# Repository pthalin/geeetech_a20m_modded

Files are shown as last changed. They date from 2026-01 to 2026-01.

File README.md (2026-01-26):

# Geeetech A20M Modded

I had a ton of problems with my Geeetech A20M when printing PETG. Bad quality prints, Fillamnt stick on the nozzle, Hotend clogs, Print not sticking to build plate, and so on. Therefore I decide to rebuild it to better fit my needs. After these changes it feels like a whole new printer! This is not a complet guide but if you are a tinker it should be enough to get you going. If you like this feel free to use the sponsored links below to support me! 

Donation using [Ko-Fi](https://ko-fi.com/patriksretrotech) or [PayPal](https://www.paypal.com/donate/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) are highly appreciated!

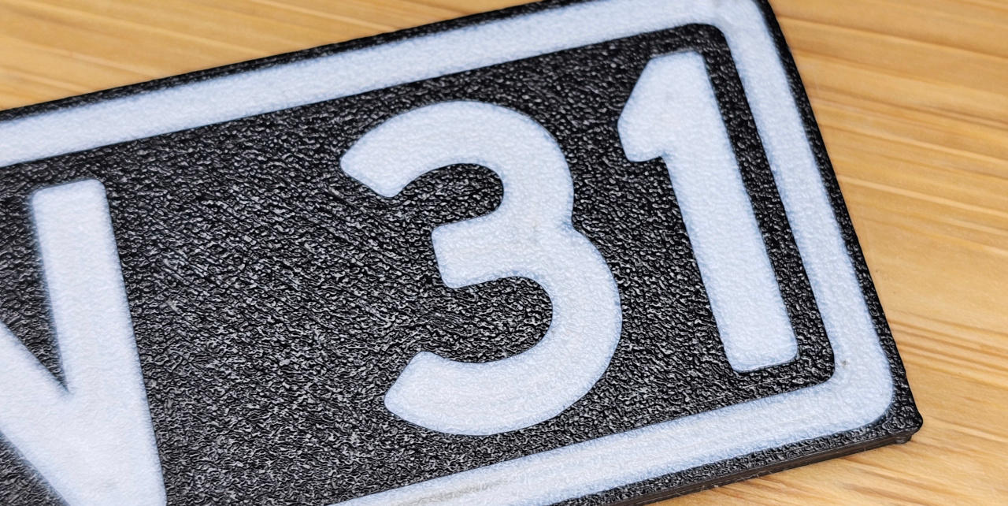
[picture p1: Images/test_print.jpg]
 

Parts (AliExpress):\
[XCR3D 2 IN 1 OUT Hotend with Heater and Sensor](https://s.click.aliexpress.com/e/_c3dWIA2b)\
[BMG Extruders Full Metal (2x Right)](https://s.click.aliexpress.com/e/_c3lZYPxh)\
[Trianglelab 3D Touch](https://s.click.aliexpress.com/e/_c2QazP8F) + [Short cable with dupont connector](https://s.click.aliexpress.com/e/_c3YiJ9rv)\
[PEI Build Plate with magnetic base](https://s.click.aliexpress.com/e/_c3RffY35)

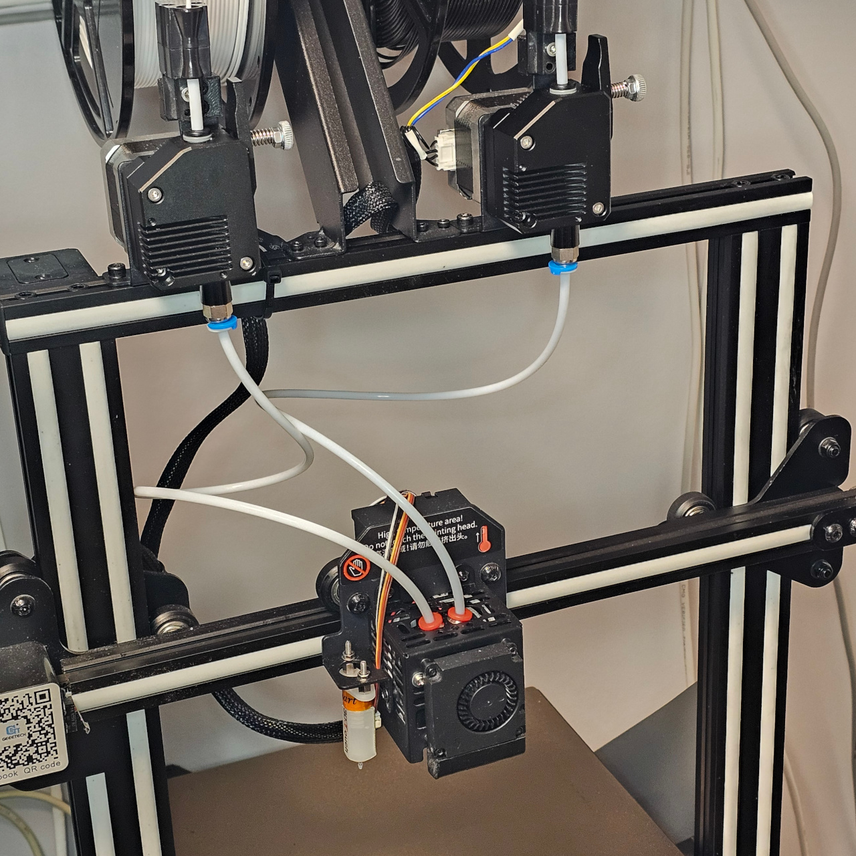
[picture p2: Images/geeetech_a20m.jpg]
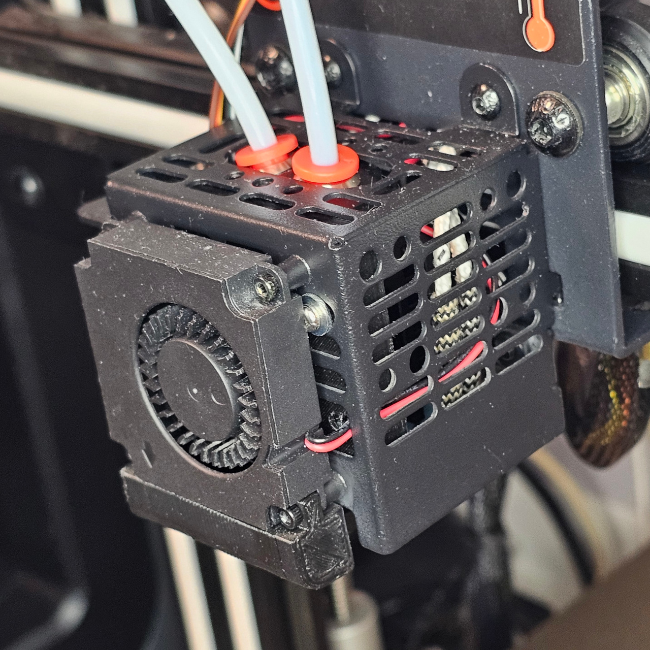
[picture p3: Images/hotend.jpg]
 

To mount the new Hotend a [mounting plate](Hotend/hotend_mount.stl) needs to be printed. 

Wiring of hotend\
 

For the modifications a custom config of [Marlin 2.0 firmware](Marlin/) is needed.\
Build it with [Visual Studio Code](https://code.visualstudio.com/download) using the [Auto Build Marlin](https://marlinfw.org/docs/basics/auto_build_marlin.html) extension to build and flash the firmware.

**IMPORTANT!** Do these steps BEFORE trying to do any prints:
1. Z-offset needs to be set correctly.
2. Run auto bed leveling.
3. Do first layer calibration.
4. Use the calibration in OrcaSlicer to fine tune your settings.

I use OrcaSlicer with the these settings: [Exported Settings](OrcaSlicer/)

I also run a Raspberry Pi with Octopi. This is convenient as you can upload print directly from OrcaSlice without fiddeling with SD Cards. I have added a realy on the cords to the printer so I can start it remotely. \
Install Octopi with Raspberry Pi Imager and load [config backup](Octopi/) (User/Password: octopi/octopi).

I strongly recommand buying a simple a fillamnt dryer. I was sceptical but this gives a huge improvement in the print results with smoother surfaces! I use a [Sunlu S2 Filament Dryer](https://s.click.aliexpress.com/e/_c3yCW3Xv)

XCR3D 2 In 1 out hotend. Not mixing colors, but PEGT is not mixing well anyway and I prefere clean colors.\
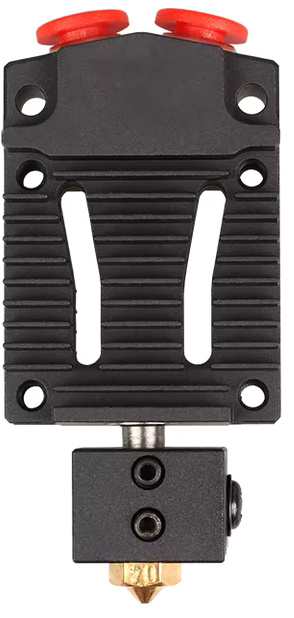
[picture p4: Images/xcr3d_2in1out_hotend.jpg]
[](https://s.click.aliexpress.com/e/_c3dWIA2b)

BMG Extruder with dual gears that ensure consisten feeding.\
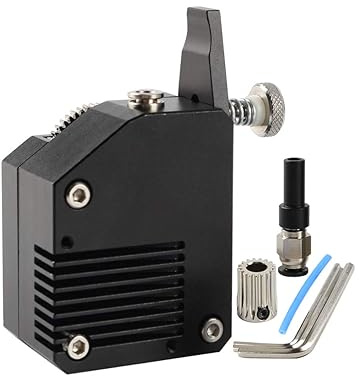
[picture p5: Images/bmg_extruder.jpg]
[](https://s.click.aliexpress.com/e/_c3lZYPxh)

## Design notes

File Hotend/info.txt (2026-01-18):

Downloaded from:
https://cults3d.com/en/3d-model/tool/btt-2-in-1-out-mount-revised-a10m

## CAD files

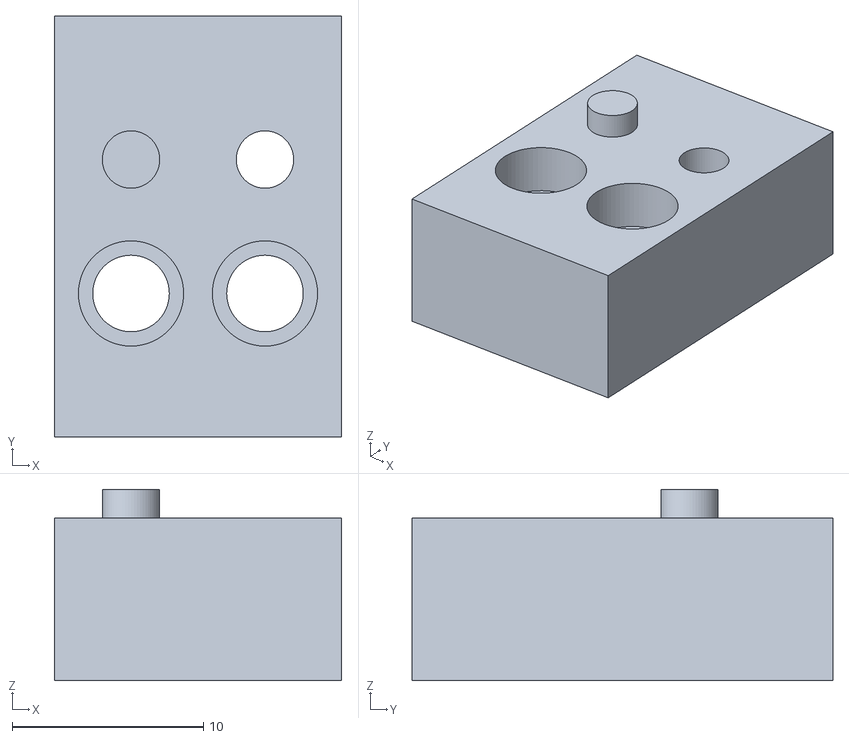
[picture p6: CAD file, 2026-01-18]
FilamentSensor/sensor_plate_a20m.stl
15.0 x 22.0 x 10.0

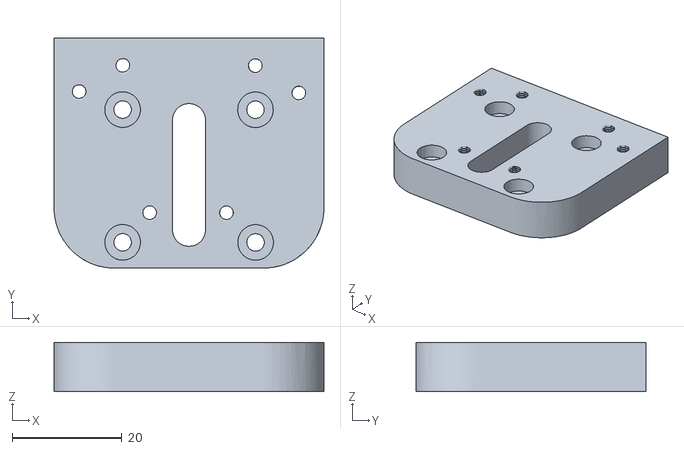
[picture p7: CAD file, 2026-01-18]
Hotend/hotend_mount.stl
49.2 x 42.0 x 9.00

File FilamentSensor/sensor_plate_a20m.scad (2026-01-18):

d = 4;
h=8.5;
b=22;
l=15;
cc=7;
OF = 7;
FNN = 60;
    union() {
difference() {
    cube([l,b,h],center=false);
        union() {
            translate([4,7.5,0]) cylinder(h=40, r=d/2, $fn=FNN, center=true);
            translate([4+cc,7.5,0]) cylinder(h=40, r=d/2, $fn=FNN, center=true);

            translate([4,7.5,h-1.5]) cylinder(h=3, r=5.5/2, $fn=FNN, center=true);
            translate([4+cc,7.5,h-1.5]) cylinder(h=3, r=5.5/2, $fn=FNN, center=true);        

         
            translate([4+cc,7.5+OF,0]) cylinder(h=40, r=3/2, $fn=FNN, center=true);
        }
    }
    translate([4,7.5+OF,h+0.5]) cylinder(h=2, r=3/2, $fn=FNN, center=true);
}

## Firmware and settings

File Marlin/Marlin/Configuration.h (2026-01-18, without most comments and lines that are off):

#pragma once
#define CONVERT_TO_CYCLOPS //Disable mixing (8 virtual extruders) & use single nozzle control system (2 physical extruders)
#define CONFIGURATION_H_VERSION 02010300
#define STRING_CONFIG_H_AUTHOR "(Vert)" // Who made the changes.
  #define MOTHERBOARD BOARD_GT2560_V3_A20
#define SERIAL_PORT 0
#define BAUDRATE 250000
#define X_DRIVER_TYPE  A4988
#define Y_DRIVER_TYPE  A4988
#define Z_DRIVER_TYPE  A4988
#define E0_DRIVER_TYPE A4988
#define E1_DRIVER_TYPE A4988
  #define EXTRUDERS 2
#define DEFAULT_NOMINAL_FILAMENT_DIA 1.75
  #define SINGLENOZZLE
  #define SINGLENOZZLE_STANDBY_TEMP
  #define SINGLENOZZLE_STANDBY_FAN
#define TEMP_SENSOR_0 5
#define TEMP_SENSOR_1 0
#define TEMP_SENSOR_2 0
#define TEMP_SENSOR_3 0
#define TEMP_SENSOR_4 0
#define TEMP_SENSOR_5 0
#define TEMP_SENSOR_6 0
#define TEMP_SENSOR_7 0
#define TEMP_SENSOR_BED 1
#define TEMP_SENSOR_PROBE 0
#define TEMP_SENSOR_CHAMBER 0
#define TEMP_SENSOR_COOLER 0
#define TEMP_SENSOR_BOARD 0
#define TEMP_SENSOR_REDUNDANT 0
#define DUMMY_THERMISTOR_998_VALUE  25
#define DUMMY_THERMISTOR_999_VALUE 100
#if TEMP_SENSOR_IS_MAX_TC(0)
  #define MAX31865_SENSOR_OHMS_0      100 // (Ω) Typically 100 or 1000 (PT100 or PT1000)
  #define MAX31865_CALIBRATION_OHMS_0 430 // (Ω) Typically 430 for Adafruit PT100; 4300 for Adafruit PT1000
#endif
#if TEMP_SENSOR_IS_MAX_TC(1)
  #define MAX31865_SENSOR_OHMS_1      100
  #define MAX31865_CALIBRATION_OHMS_1 430
#endif
#if TEMP_SENSOR_IS_MAX_TC(2)
  #define MAX31865_SENSOR_OHMS_2      100
  #define MAX31865_CALIBRATION_OHMS_2 430
#endif
#if HAS_E_TEMP_SENSOR
  #define TEMP_RESIDENCY_TIME         10  // (seconds) Time to wait for hotend to "settle" in M109
  #define TEMP_WINDOW                  1  // (°C) Temperature proximity for the "temperature reached" timer
  #define TEMP_HYSTERESIS              3  // (°C) Temperature proximity considered "close enough" to the target
#endif
#if TEMP_SENSOR_BED
  #define TEMP_BED_RESIDENCY_TIME     10  // (seconds) Time to wait for bed to "settle" in M190
  #define TEMP_BED_WINDOW              1  // (°C) Temperature proximity for the "temperature reached" timer
  #define TEMP_BED_HYSTERESIS          3  // (°C) Temperature proximity considered "close enough" to the target
#endif
#if TEMP_SENSOR_CHAMBER
  #define TEMP_CHAMBER_RESIDENCY_TIME 10  // (seconds) Time to wait for chamber to "settle" in M191
  #define TEMP_CHAMBER_WINDOW          1  // (°C) Temperature proximity for the "temperature reached" timer
  #define TEMP_CHAMBER_HYSTERESIS      3  // (°C) Temperature proximity considered "close enough" to the target
#endif
#if TEMP_SENSOR_REDUNDANT
  #define TEMP_SENSOR_REDUNDANT_SOURCE    E1  // The sensor that will provide the redundant reading.
  #define TEMP_SENSOR_REDUNDANT_TARGET    E0  // The sensor that we are providing a redundant reading for.
  #define TEMP_SENSOR_REDUNDANT_MAX_DIFF  10  // (°C) Temperature difference that will trigger a print abort.
#endif
#define HEATER_0_MINTEMP   0
#define HEATER_1_MINTEMP   0
#define HEATER_2_MINTEMP   0
#define HEATER_3_MINTEMP   0
#define HEATER_4_MINTEMP   0
#define HEATER_5_MINTEMP   0
#define HEATER_6_MINTEMP   0
#define HEATER_7_MINTEMP   0
#define BED_MINTEMP        0
#define CHAMBER_MINTEMP    0
#define HEATER_0_MAXTEMP 275
#define HEATER_1_MAXTEMP 275
#define HEATER_2_MAXTEMP 275
#define HEATER_3_MAXTEMP 275
#define HEATER_4_MAXTEMP 275
#define HEATER_5_MAXTEMP 275
#define HEATER_6_MAXTEMP 275
#define HEATER_7_MAXTEMP 275
#define BED_MAXTEMP      150
#define CHAMBER_MAXTEMP  60
#define HOTEND_OVERSHOOT 15   // (°C) Forbid temperatures over MAXTEMP - OVERSHOOT
#define BED_OVERSHOOT    10   // (°C) Forbid temperatures over MAXTEMP - OVERSHOOT
#define COOLER_OVERSHOOT  2   // (°C) Forbid temperatures closer than OVERSHOOT
#define PIDTEMP          // See the PID Tuning Guide at https://reprap.org/wiki/PID_Tuning
#define BANG_MAX 190 //255     // Limits current to nozzle while in bang-bang mode; 255=full current
#define PID_MAX BANG_MAX // Limits current to nozzle while PID is active (see PID_FUNCTIONAL_RANGE below); 255=full current
#define PID_K1 0.95      // Smoothing factor within any PID loop
    #define DEFAULT_Kp 9.58
    #define DEFAULT_Ki 0.50
    #define DEFAULT_Kd 45.51
#define PIDTEMPBED
#define MAX_BED_POWER 255 // limits duty cycle to bed; 255=full current
  #define DEFAULT_bedKp 182.46   // 175.68 189.95
  #define DEFAULT_bedKi 35.92    //  34.59  37.40
  #define DEFAULT_bedKd 231.70   // 223.07 241.19
#define MAX_CHAMBER_POWER 255 // limits duty cycle to chamber heater; 255=full current
  #define PID_FUNCTIONAL_RANGE 10 // If the temperature difference between the target temperature and the actual temperature
#define PREVENT_COLD_EXTRUSION
#define EXTRUDE_MINTEMP 170
#define PREVENT_LENGTHY_EXTRUDE
#define EXTRUDE_MAXLENGTH 450
#define THERMAL_PROTECTION_HOTENDS // Enable thermal protection for all extruders
#define THERMAL_PROTECTION_BED     // Enable thermal protection for the heated bed
#define THERMAL_PROTECTION_CHAMBER // Enable thermal protection for the heated chamber
#define THERMAL_PROTECTION_COOLER  // Enable thermal protection for the laser cooling
#define USE_XMIN_PLUG
#define USE_YMIN_PLUG
#define USE_ZMIN_PLUG
#define ENDSTOPPULLUPS
#define X_MIN_ENDSTOP_INVERTING true  // Set to true to invert the logic of the endstop.
#define Y_MIN_ENDSTOP_INVERTING true  // Set to true to invert the logic of the endstop.
#define Z_MIN_ENDSTOP_INVERTING false  // Set to true to invert the logic of the endstop.
#define X_MAX_ENDSTOP_INVERTING true  // Set to true to invert the logic of the endstop.
#define Y_MAX_ENDSTOP_INVERTING true  // Set to true to invert the logic of the endstop.
#define Z_MAX_ENDSTOP_INVERTING true  // Set to true to invert the logic of the endstop.
#define Z_MIN_PROBE_ENDSTOP_INVERTING false  // Set to true to invert the logic of the probe.
#define ENDSTOP_NOISE_THRESHOLD 2
#define DETECT_BROKEN_ENDSTOP
  #define DISTINCT_E_FACTORS
#define DEFAULT_AXIS_STEPS_PER_UNIT   { 80.3, 80.80, 400, 394.9 }
#define DEFAULT_MAX_FEEDRATE          { 500, 500, 5, 25 }
#define DEFAULT_MAX_ACCELERATION      { 500, 500, 100, 5000 }
#define DEFAULT_ACCELERATION          500    // X, Y, Z and E acceleration for printing moves
#define DEFAULT_RETRACT_ACCELERATION  500    // E acceleration for retracts
#define DEFAULT_TRAVEL_ACCELERATION   500    // X, Y, Z acceleration for travel (non printing) moves
#define DEFAULT_EJERK    5.0  // May be used by Linear Advance
  #define JUNCTION_DEVIATION_MM 0.013  // (mm) Distance from real junction edge
  #define JD_HANDLE_SMALL_SEGMENTS    // Use curvature estimation instead of just the junction angle
#define S_CURVE_ACCELERATION
#define Z_MIN_PROBE_USES_Z_MIN_ENDSTOP_PIN
  #define BLTOUCH
#define NOZZLE_TO_PROBE_OFFSET { -40, 0, 0 }
#define PROBING_MARGIN 0
#define XY_PROBE_FEEDRATE (50*60)
#define Z_PROBE_FEEDRATE_FAST (10*60)
#define Z_PROBE_FEEDRATE_SLOW Z_PROBE_FEEDRATE_FAST
#define Z_CLEARANCE_DEPLOY_PROBE    5 // Z Clearance for Deploy/Stow
#define Z_CLEARANCE_BETWEEN_PROBES  5 // Z Clearance between probe points
#define Z_CLEARANCE_MULTI_PROBE     5 // Z Clearance between multiple probes
#define Z_PROBE_LOW_POINT          -2 // Farthest distance below the trigger-point to go before stopping
#define Z_PROBE_OFFSET_RANGE_MIN -5
#define Z_PROBE_OFFSET_RANGE_MAX 5
  #define Z_MIN_PROBE_REPEATABILITY_TEST //diagnostic tool to check probe functions
#define X_ENABLE_ON 0
#define Y_ENABLE_ON 0
#define Z_ENABLE_ON 0
#define E_ENABLE_ON 0 // For all extruders
#define DISABLE_X false
#define DISABLE_Y false
#define DISABLE_Z false
#define DISABLE_E false             // Disable the extruder when not stepping
#define INVERT_X_DIR true
#define INVERT_Y_DIR true
#define INVERT_Z_DIR false
#define INVERT_E0_DIR false
#define INVERT_E1_DIR false  // unused, the A10 only has one extruder by default
#define INVERT_E2_DIR false  // unused, the A10 only has one extruder by default
#define INVERT_E3_DIR false  // unused, the A10 only has one extruder by default
#define INVERT_E4_DIR false  // unused, the A10 only has one extruder by default
#define INVERT_E5_DIR false  // unused, the A10 only has one extruder by default
#define X_HOME_DIR -1
#define Y_HOME_DIR -1
#define Z_HOME_DIR -1
#define X_BED_SIZE 245
#define Y_BED_SIZE 245
#define X_MIN_POS -1
#define Y_MIN_POS -7
#define Z_MIN_POS 0
#define X_MAX_POS X_BED_SIZE
#define Y_MAX_POS Y_BED_SIZE
#define Z_MAX_POS 250
#define MIN_SOFTWARE_ENDSTOPS
  #define MIN_SOFTWARE_ENDSTOP_X
  #define MIN_SOFTWARE_ENDSTOP_Y
  #define MIN_SOFTWARE_ENDSTOP_Z
  #define MIN_SOFTWARE_ENDSTOP_I
  #define MIN_SOFTWARE_ENDSTOP_J
  #define MIN_SOFTWARE_ENDSTOP_K
  #define MIN_SOFTWARE_ENDSTOP_U
  #define MIN_SOFTWARE_ENDSTOP_V
  #define MIN_SOFTWARE_ENDSTOP_W
#define MAX_SOFTWARE_ENDSTOPS
  #define MAX_SOFTWARE_ENDSTOP_X
  #define MAX_SOFTWARE_ENDSTOP_Y
  #define MAX_SOFTWARE_ENDSTOP_Z
  #define MAX_SOFTWARE_ENDSTOP_I
  #define MAX_SOFTWARE_ENDSTOP_J
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

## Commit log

2026-01-18 Added Marlin
    [Configuration.h, Configuration_adv.h, esp32.csv]
2026-01-18 Marlin config updated for modifications
    [Configuration.h]
2026-01-18 Added motend mount stl
    [hotend_mount.stl]
2026-01-18 Add sensor mounts
    [sensor_plate_a20m.scad, sensor_plate_a20m.stl]

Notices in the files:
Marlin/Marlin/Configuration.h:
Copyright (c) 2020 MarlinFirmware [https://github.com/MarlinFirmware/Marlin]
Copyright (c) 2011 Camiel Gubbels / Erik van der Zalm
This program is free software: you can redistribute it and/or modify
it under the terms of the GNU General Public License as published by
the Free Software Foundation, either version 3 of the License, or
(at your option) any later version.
